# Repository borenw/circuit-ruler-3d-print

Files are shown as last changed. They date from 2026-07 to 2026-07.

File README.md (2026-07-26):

# Circuit Stencil Ruler — 3D Print

A printable circuit-drafting **stencil ruler** built from the **actual symbol
artwork** in [`template_ruler.svg`](template_ruler.svg). The 19 hand-drawn
schematic symbols are parsed straight from the SVG, then only *rearranged and
resized* onto a tidy plate — the shapes themselves are unchanged.

- engraved **dual measuring scales** — centimetres (0–18 cm) along the top edge
  and inches (0–7″, with ½/¼/⅛″ ticks) along the bottom edge
- **19 faithful through-cut symbols** you trace with a pen — inverter/Schmitt,
  logic gates, latch & flip-flop blocks, MOSFETs, resistor, inductor,
  capacitor, ground, diode, op-amp, voltage/current sources, meter,
  transformer, switch, radiation source
- automatic **stencil bridges** on every enclosed island

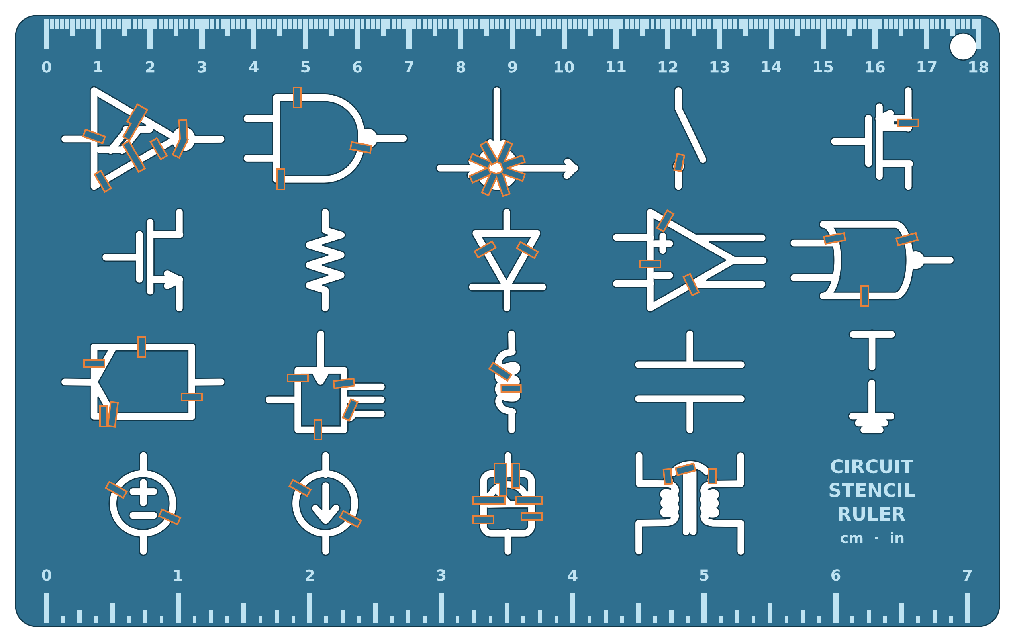
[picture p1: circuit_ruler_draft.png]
draft render


*(orange = the bridges; they are solid uncut plate in the real part)*

## Why the bridges matter

In a stencil, any symbol with a closed loop — a triangle interior, a gate body,
a circle, a rectangle, a coil eye, an output bubble — encloses an "island" of
material that would simply **drop out** once cut through. The generator detects
every island automatically (31 of them here) and ties each one back to the body
with tiny **bridges** (34 total, 1.4 mm wide, full plate thickness). The
finished model is a **single connected solid** (verified `body_count == 1`), so
nothing falls out and the ties are mechanically strong enough for repeated use.
Trace over a bridge with your pen and just close the ~1.4 mm gap freehand.

## Files

| File | What it is |
|---|---|
| `circuit_ruler.stl` | **The 3D print file.** 190 × 118 × 3 mm, watertight, one solid body. |
| `circuit_ruler_draft.png` | Top-view draft render (bridges highlighted). |
| `circuit_ruler.py` | Generator: arranges the SVG symbols, adds the scale, bridges every island. |
| `svg_source.py` | Faithful `template_ruler.svg` parser + symbol segmenter. |
| [`template_ruler.svg`](template_ruler.svg) | Original hand-drawn source artwork (unmodified). |

## Source artwork

The 19 symbols are lifted straight from this drawing —
**[`template_ruler.svg`](template_ruler.svg)**:

source artwork

## Print settings

- **Size:** 190 × 118 × 3 mm — fits any bed ≥ 200 × 130 mm.
- **Material:** PLA or PETG.
- **Layer height:** 0.16–0.20 mm.
- **Walls / perimeters:** 3+ (gives the thin plate and the bridges their strength).
- **Infill:** 30–100 %.
- **Supports:** none — flat plate, printed engraved-face up.

Symbol channels are **1.5 mm** wide (trace with a fine pen or 0.5–0.7 mm
pencil); the engraved scales are **0.8 mm** deep.

## Regenerating / customizing

Requires Python 3 with `numpy`, `shapely`, `trimesh`, `manifold3d`,
`mapbox_earcut`, `matplotlib`.

```bash
python3 circuit_ruler.py          # draft PNG only
python3 circuit_ruler.py --stl    # draft PNG + STL
```

Tune the constants at the top of `circuit_ruler.py`: `COLS`/`ROWS` (grid),
`L`/`W`/`T` (plate), `CHANNEL` (slot width), `BRIDGE_W` (tie width),
`ENGRAVE_DEPTH`. Bridge placement is fully automatic — change the layout and it
re-solves which islands need tying.

## License

CC BY 4.0 — free to print, share, and remix with attribution.

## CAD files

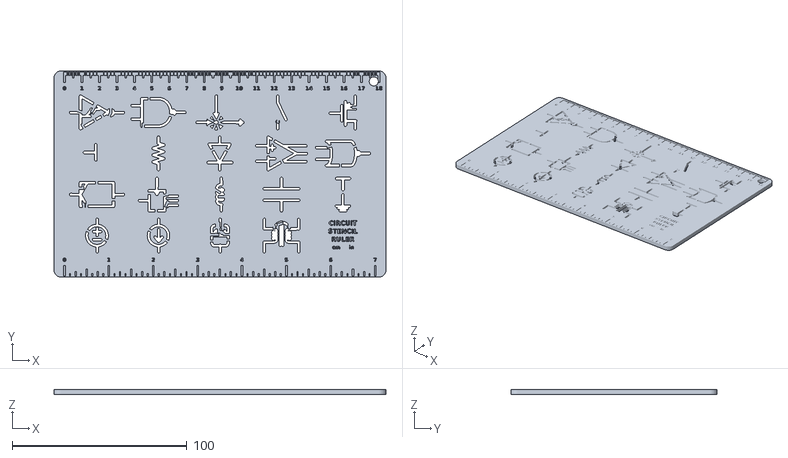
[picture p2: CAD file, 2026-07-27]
circuit_ruler.stl
190.0 x 118.0 x 3.00

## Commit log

2026-07-26 Circuit stencil ruler: STL + generator + draft render
    Parametric circuit-drafting stencil ruler (180x72x3 mm): engraved mm/cm
    scale plus 11 through-cut schematic symbols (R, R-box, C, L, diode,
    battery, ground, switch, AC source, lamp, NPN) and a node dot. Derived
    from the hand-drawn template_ruler.svg source art.
    [circuit_ruler.stl]
2026-07-26 Faithful SVG symbols + automatic stencil bridges
    Rebuild the stencil from the ACTUAL template_ruler.svg artwork: svg_source.py
    parses the paths (M/L/C/Z + matrix transforms), flattens beziers and segments
    the drawing into its 19 real schematic symbols. circuit_ruler.py now only
    arranges + sizes those true shapes into a 5x4 grid (190x118x3 mm).
    Every enclosed island (triangle/gate/circle/rect/coil/bubble interiors) is
    detected and tied back to the body with tiny 1.4 mm bridges (31 islands, 34
    bridges) so nothing drops out of the stencil -> the STL is a single connected
    solid (body_count==1, watertight). Also fixed ring-glyph (0/8) text rendering.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
    [circuit_ruler.stl]
2026-07-26 Fix undersized symbols: trim leads so bodies drive the scale
    The voltage/current sources (and other lead-heavy symbols) were ~80% wire, so
    fitting them to a cell shrank the circle until the +/- and arrow blobbed into
    the 1.5mm channel. svg_source now trims long straight terminal leads that run
    parallel to the symbol's long axis (keeps plates/bars/switch levers), so the
    BODY sets the scale. Sources, resistor, diode, inductor, cap now render clean.
    Still one watertight solid (body_count==1); 35 islands / 44 bridges.
    [circuit_ruler.stl]
2026-07-26 Add dual scale: cm on top edge, inches (1/8) on bottom edge
    Bottom edge now carries a 0-7 inch scale with 1/2, 1/4, 1/8 ticks; the title
    moves into the empty bottom-right cell as a title block. Still one watertight
    solid (body_count==1).
    [circuit_ruler.stl]
2026-07-27 Full-bleed higher-res draft PNG (fills frame, no title band)
    The draft looked shrunk when a browser scaled it: the image had a title band
    and wide white margins so the ruler filled only part of the frame. Render it
    full-bleed (plate fills the image) at 260 dpi -> 2548x1612. Move the unit note
    (cm / in) into the title block so it isn't clipped at the tight right edge.
    [circuit_ruler.stl]
